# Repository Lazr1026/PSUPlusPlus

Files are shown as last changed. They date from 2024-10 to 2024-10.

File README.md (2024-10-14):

# wiiu-psu
The wiiu-psu (or PSU++) is a regulator board for the Wii U, minus the core rails (1v/1.15v).
It is based off the PSU-Plus, so all rails have a limit of 3A (this only really matters for 5v).

### Features
- All low-current regulators required for the Wii U to function.
- Bonus 3v3 rail (STBY) for the RTC to power on the system.
- 1.25v regulator for WUP-01 motherboards (or if you wanted to remove the stock one).
    - 1.25v can be enabled/disabled with a simple jumper.

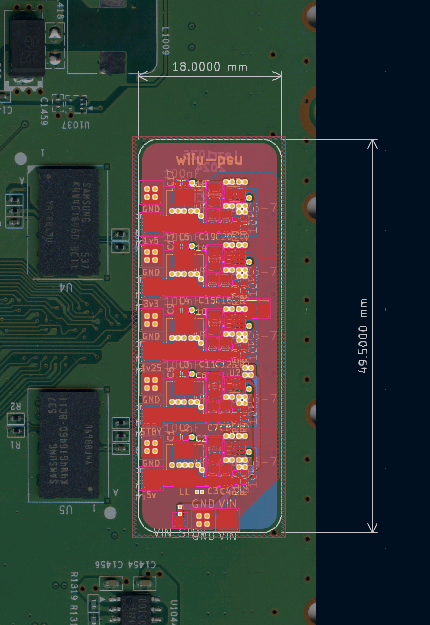
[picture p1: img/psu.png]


The intent is to be used for the Wii U Mini, but if you find another use for this board, have at it!  
There are two VIN pads. The smaller one is used to power the STBY regulator, while the bigger one is to power all of the other regulators.

### Credits
[CrazyGadget](https://github.com/CrazyGadgetMods) / [YveltalGriffin](https://github.com/mackieks): The original PSU-Plus regulator board.  
[BitBuilt](https://bitbuilt.net/): Being pretty fucking cool.

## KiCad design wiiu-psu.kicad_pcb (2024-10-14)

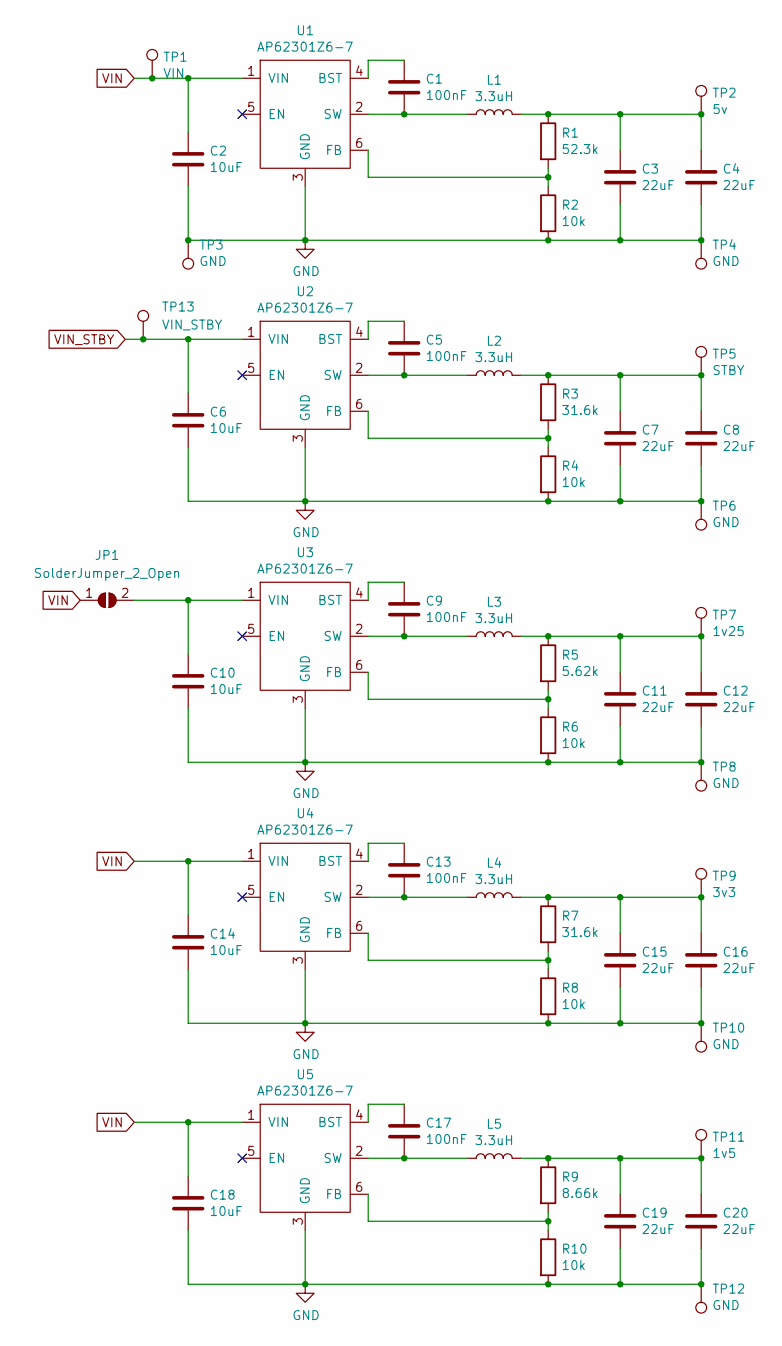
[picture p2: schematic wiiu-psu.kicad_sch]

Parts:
C1, C5, C9, C13, C17: 100nF; C_0402_1005Metric
C2, C6, C10, C14, C18: 10uF; C_0805_2012Metric
C3, C4, C7, C8, C11, C12, C15, C16, C19, C20: 22uF; C_0603_1608Metric
JP1: SolderJumper_2_Open; SolderJumper-2_P1.3mm_Open_Pad1.0x1.5mm
L1, L2, L3, L4, L5: 3.3uH; 1919
R1: 52.3k; R_0402_1005Metric
R2, R4, R6, R8, R10: 10k; R_0402_1005Metric
R3, R7: 31.6k; R_0402_1005Metric
R5: 5.62k; R_0402_1005Metric
R9: 8.66k; R_0402_1005Metric
TP1: VIN; TestPoint_Pad_2.0x2.0mm
TP2: 5v; TestPoint_Pad_2.0x2.0mm
TP3, TP4, TP6, TP8, TP10, TP12: GND; TestPoint_Pad_2.0x2.0mm
TP5: STBY; TestPoint_Pad_2.0x2.0mm
TP7: 1v25; TestPoint_Pad_2.0x2.0mm
TP9: 3v3; TestPoint_Pad_2.0x2.0mm
TP11: 1v5; TestPoint_Pad_2.0x2.0mm
TP13: VIN_STBY; TestPoint_Pad_1.0x1.0mm
U1, U2, U3, U4, U5: AP62301Z6-7; SOT-563mod

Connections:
GND: C2.1, C3.2, C4.2, C6.1, C7.2, C8.2, C10.1, C11.2, C12.2, C14.1, C15.2, C16.2, C18.1, C19.2, C20.2, R2.2, R4.2, R6.2, R8.2, R10.2, TP3.1, TP4.1, TP6.1, TP8.1, TP10.1, TP12.1, U1.3 (GND), U2.3 (GND), U3.3 (GND), U4.3 (GND), U5.3 (GND)
unnamed: C3.1, C4.1, L1.2, R1.1, TP2.1
unnamed: C7.1, C8.1, L2.2, R3.1, TP5.1
unnamed: C11.1, C12.1, L3.2, R5.1, TP7.1
unnamed: C15.1, C16.1, L4.2, R7.1, TP9.1
unnamed: C19.1, C20.1, L5.2, R9.1, TP11.1
unnamed: C10.2, JP1.2 (B), U3.1 (VIN)
unnamed: C1.1, U1.4 (BST)
unnamed: R1.2, R2.1, U1.6 (FB)
unnamed: C1.2, L1.1, U1.2 (SW)
unnamed: C5.1, U2.4 (BST)
unnamed: R3.2, R4.1, U2.6 (FB)
unnamed: C5.2, L2.1, U2.2 (SW)
unnamed: C9.1, U3.4 (BST)
unnamed: R5.2, R6.1, U3.6 (FB)
unnamed: C9.2, L3.1, U3.2 (SW)
unnamed: C13.1, U4.4 (BST)
unnamed: R7.2, R8.1, U4.6 (FB)
unnamed: C13.2, L4.1, U4.2 (SW)
unnamed: C17.1, U5.4 (BST)
unnamed: R9.2, R10.1, U5.6 (FB)
unnamed: C17.2, L5.1, U5.2 (SW)
VIN: C2.2, C14.2, C18.2, JP1.1 (A), TP1.1, U1.1 (VIN), U4.1 (VIN), U5.1 (VIN)
VIN_STBY: C6.2, TP13.1, U2.1 (VIN)

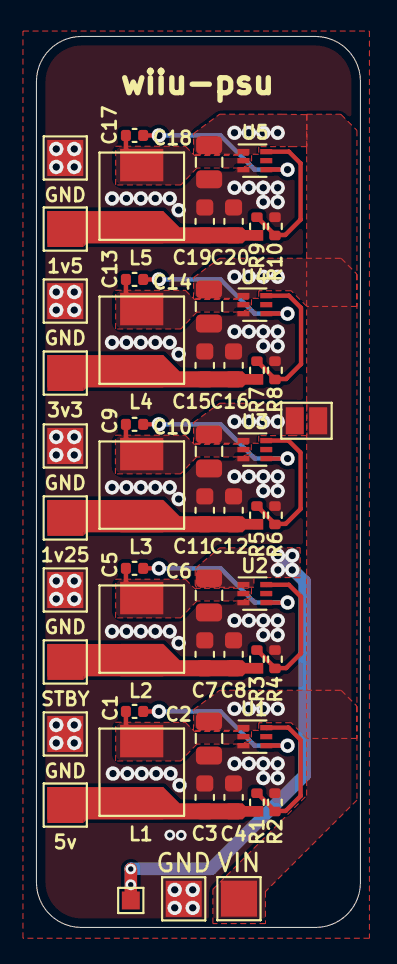
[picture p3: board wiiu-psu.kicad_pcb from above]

Board: 2 copper layers, 18.0 x 49.5 mm, 54 parts (0 on the bottom side), 24 nets.
